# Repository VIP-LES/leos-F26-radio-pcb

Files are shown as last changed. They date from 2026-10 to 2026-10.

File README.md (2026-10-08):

# LEOS Radio PCB

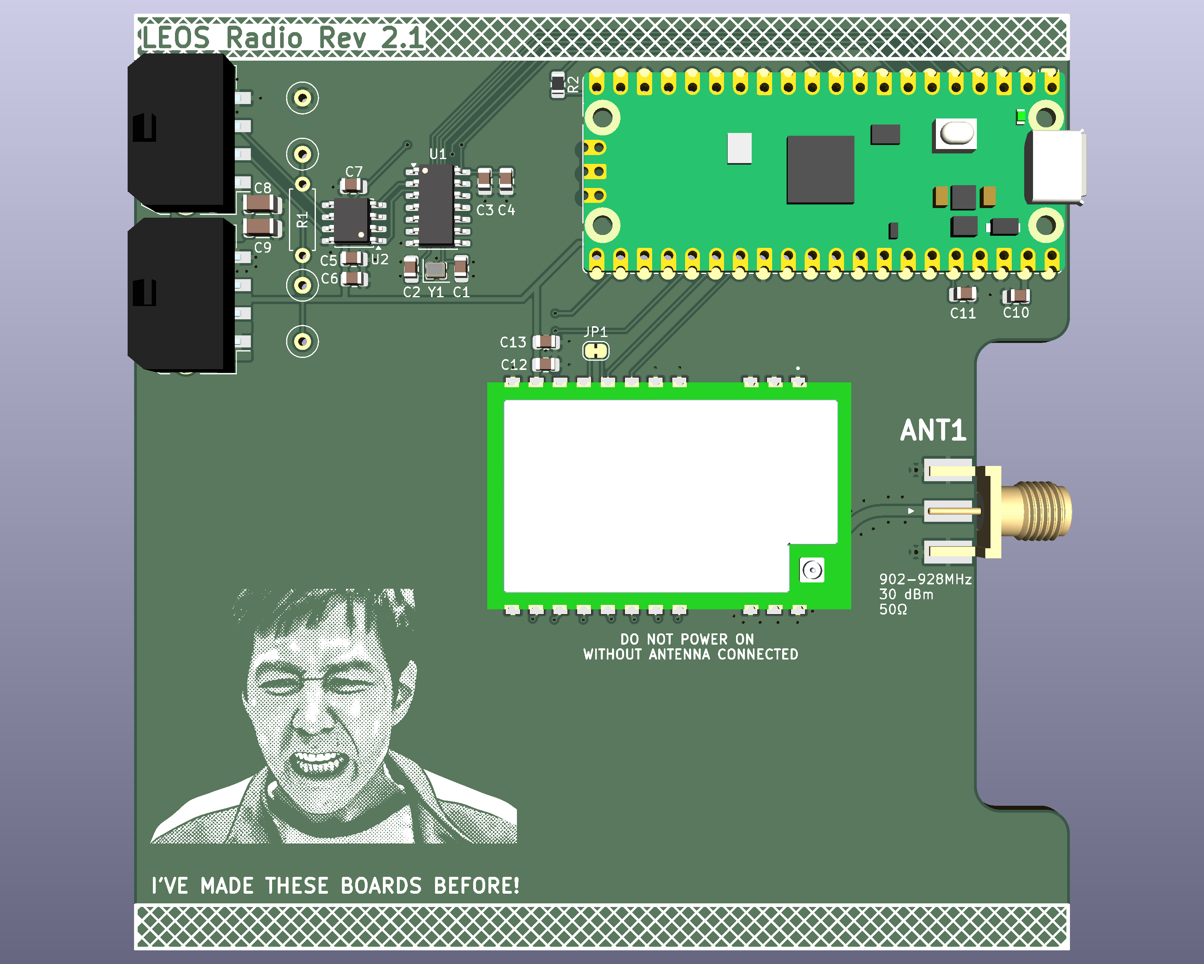
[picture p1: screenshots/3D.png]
3D render of the LEOS Radio PCB


This repository contains the KiCad schematic and PCB layout for the LEOS Radio PCB made fall 2026. The board integrates a Raspberry Pi Pico, an E22-900M30S LoRa radio module, and a CAN-FD interface.

The Raspberry Pi Pico communicates with the radio module through SPI1 and the MCP2518FD CAN-FD controller through SPI0. An MCP2562FD transceiver connects the CAN controller to the LEOS CAN bus. An SMA connector provides the connection for an external antenna.

## Board Overview
Main hardware functions:
- Wireless communication: E22-900M30S LoRa radio module provides wireless transmission and reception through an external antenna connected to the SMA connector.
- CAN-FD communication: MCP2518FD controller and MCP2562FD transceiver provide the interface to the LEOS CAN bus.
- Microcontroller control: Pico interfaces with the radio module and CAN controller through separate SPI buses. Additional GPIO connections provide radio reset, busy monitoring, interrupt, and receive-enable signals.

## Electrical Design
- Board supply: 5 V
- Microcontroller: Raspberry Pi Pico, as labeled in the schematic
- Radio module: E22-900M30S
- CAN-FD controller: MCP2518FD
- CAN-FD transceiver: MCP2562FD
- Bus connectors: Two four-pin MicroFit connectors

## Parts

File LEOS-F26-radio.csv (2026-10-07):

Reference | Qty | Value | Footprint | Manufacturer | MPN | Digikey | Description
A1 | 1 | RaspberryPi Pico | Module:RaspberryPi_Pico_Common_Unspecified | Pimoroni | PIM724 | 1778-PIM724-ND | Pimoroni Pico Plus 2
ANT1 | 1 | 900MHz SMA | Connector_Coaxial:SMA_Molex_73251-1153_EdgeMount_Horizontal | Molex | 0732511153 | 900-0732511153-ND | coaxial connector (BNC, SMA, SMB, SMC, Cinch/RCA, LEMO, ...)
C1,C2 | 2 | 10p | Capacitor_SMD:C_0805_2012Metric | Samsung Electro-Mechanics | CL21C100CBANNNC | 1276-2561-1-ND | 10pF 50V C0G/NP0 0805
C3,C5,C7,C10,C12 | 5 | 0.1u | Capacitor_SMD:C_0805_2012Metric | Samsung Electro-Mechanics | CL21B104KBCNNNC | 1276-1003-1-ND | 0.1uF 50V X7R 0805
C4,C6,C13 | 3 | 1u | Capacitor_SMD:C_0805_2012Metric | KEMET | C0805C105K3RACTU | 399-C0805C105K3RACTUCT-ND | CAP CER 1UF 25V X7R 0805
C8,C9 | 2 | 22u | Capacitor_SMD:C_1206_3216Metric | Samsung Electro-Mechanics | CL31B226MPHNNNE | 1276-3148-1-ND | 22uF 10V X7R 1206
C11 | 1 | 10u | Capacitor_SMD:C_0805_2012Metric | Samsung Electro-Mechanics | CL21B106KOQNNNE | 1276-2872-1-ND | CAP CER 10UF 16V X7R 0805
J1,J2 | 2 | MicroFit_1x4 | LEOS:Molex_MicroFit3.0_43650-0410_1x04_Horizontal | Molex | 0436500409 | WM1882CT-ND | Molex MicroFit3.0 1x4 Bus Connector
R2 | 1 | 10k | Resistor_SMD:R_0805_2012Metric | Vishay Dale | CRCW080510K0FKEA | 541-10.0KCCT-ND | RES SMD 10K OHM 1% 1/8W 0805
U1 | 1 | MCP2518FD | Package_SO:SOIC-14_3.9x8.7mm_P1.27mm | Microchip | MCP2518FDT-E/SL | MCP2518FDT-E/SLCT-ND | External CAN FD Controller with SPI Interface
U2 | 1 | MCP2562FD | Package_SO:SOIC-8_3.9x4.9mm_P1.27mm | Microchip | MCP2562FDT-H/SN | MCP2562FDT-E/SNCT-ND | High-Speed CAN Flexible Data Rate Transceiver
U3 | 1 | E22-900M30S | LEOS:XCVR_E22-900M30S |  |  |  | SX1262 868/915 MHz 1w SPI LoRa Module
Y1 | 1 | 40 MHz | Crystal:Crystal_SMD_2016-4Pin_2.0x1.6mm | ECS Inc, | ECS-400-10-37B2-CKY-TR | 50-ECS-400-10-37B2-CKY-TRCT-ND | 40 MHz ±10ppm Crystal 10pF 40 Ohms SMD2016

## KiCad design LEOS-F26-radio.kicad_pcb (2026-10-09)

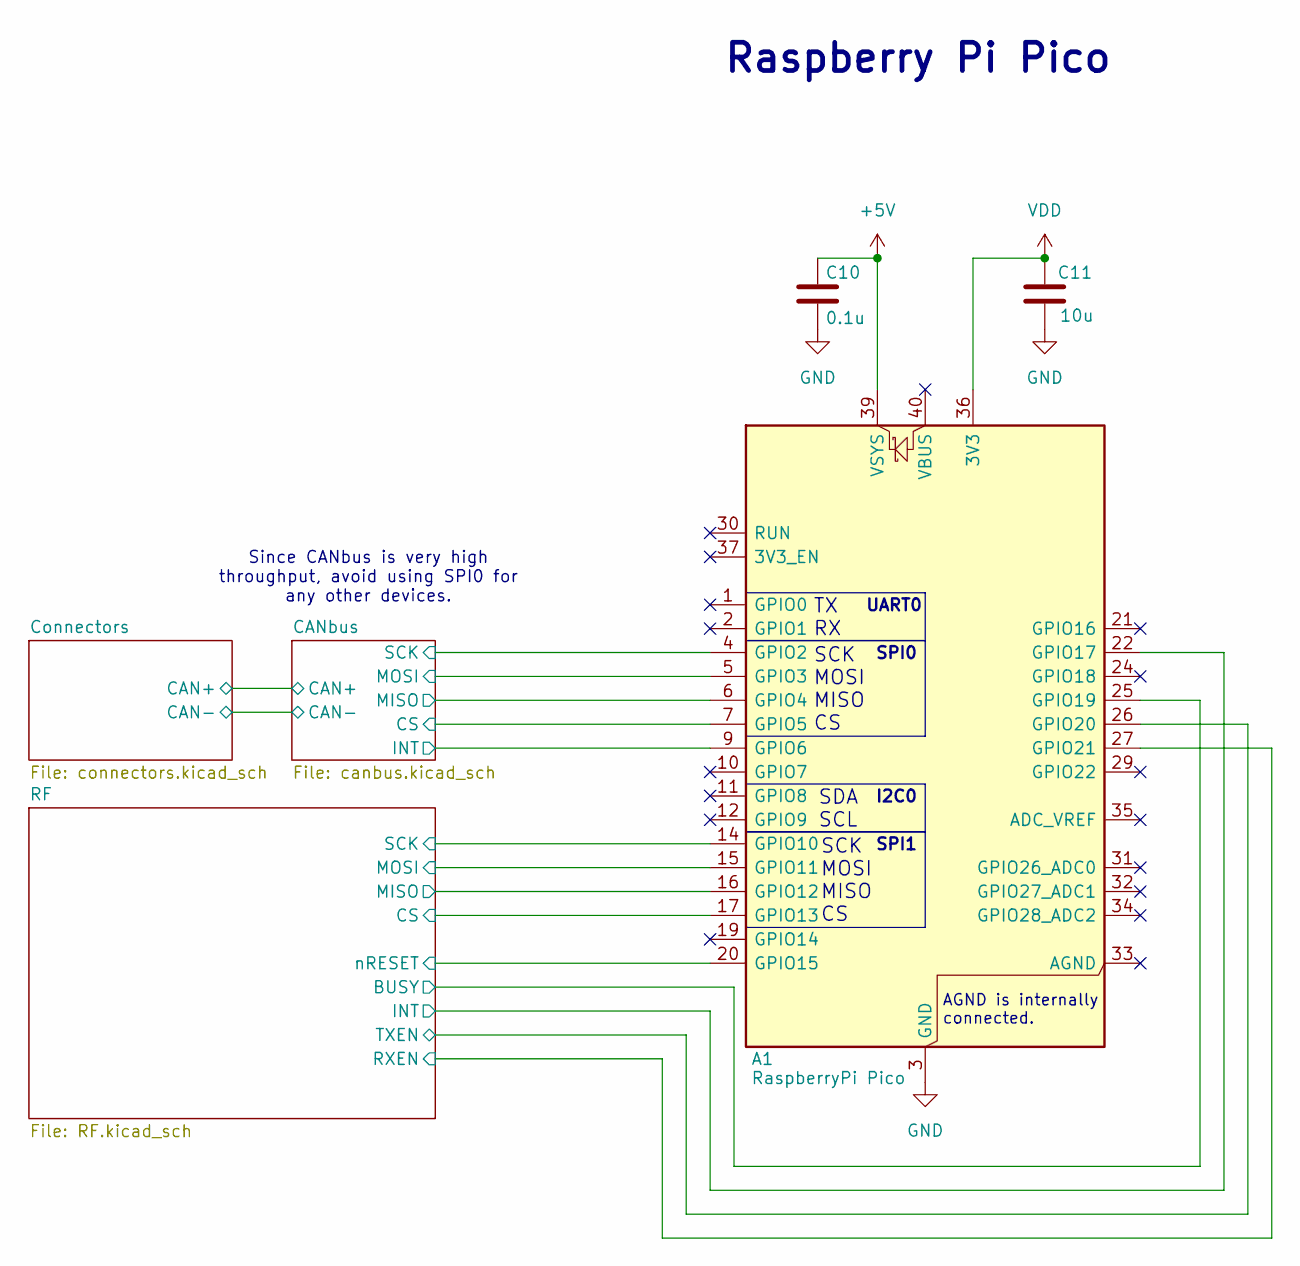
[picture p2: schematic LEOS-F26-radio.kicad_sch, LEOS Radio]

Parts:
A1: RaspberryPi Pico; RaspberryPi_Pico_Common_Unspecified; MPN PIM724; Digikey 1778-PIM724-ND
C10: 0.1u; C_0805_2012Metric; MPN CL21B104KBCNNNC; Digikey 1276-1003-1-ND
C11: 10u; C_0805_2012Metric; MPN CL21B106KOQNNNE; Digikey 1276-2872-1-ND

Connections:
+5V: A1.39 (VSYS), C10.1; also elsewhere on the board
/CANbus/CS: A1.7 (GPIO5); also elsewhere on the board
/CANbus/INT: A1.9 (GPIO6); also elsewhere on the board
/CANbus/MISO: A1.6 (GPIO4); also elsewhere on the board
/CANbus/MOSI: A1.5 (GPIO3); also elsewhere on the board
/CANbus/SCK: A1.4 (GPIO2); also elsewhere on the board
/RF/BUSY: A1.25 (GPIO19); also elsewhere on the board
/RF/CS: A1.17 (GPIO13); also elsewhere on the board
/RF/INT: A1.22 (GPIO17); also elsewhere on the board
/RF/MISO: A1.16 (GPIO12); also elsewhere on the board
/RF/MOSI: A1.15 (GPIO11); also elsewhere on the board
/RF/RXEN: A1.27 (GPIO21); also elsewhere on the board
/RF/SCK: A1.14 (GPIO10); also elsewhere on the board
/RF/TXEN: A1.26 (GPIO20); also elsewhere on the board
/RF/nRESET: A1.20 (GPIO15); also elsewhere on the board
GND: A1.3 (GND), A1.8 (GND), A1.13 (GND), A1.18 (GND), A1.23 (GND), A1.28 (GND), A1.38 (GND), C10.2, C11.2; also elsewhere on the board
VDD: A1.36 (3V3), C11.1; also elsewhere on the board

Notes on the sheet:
SPI1
Raspberry Pi Pico
SCK MOSI MISO CS
Since CANbus is very high throughput, avoid using SPI0 for any other devices.
SPI0
SDA SCL
TX RX
UART0
I2C0
AGND is internally connected.

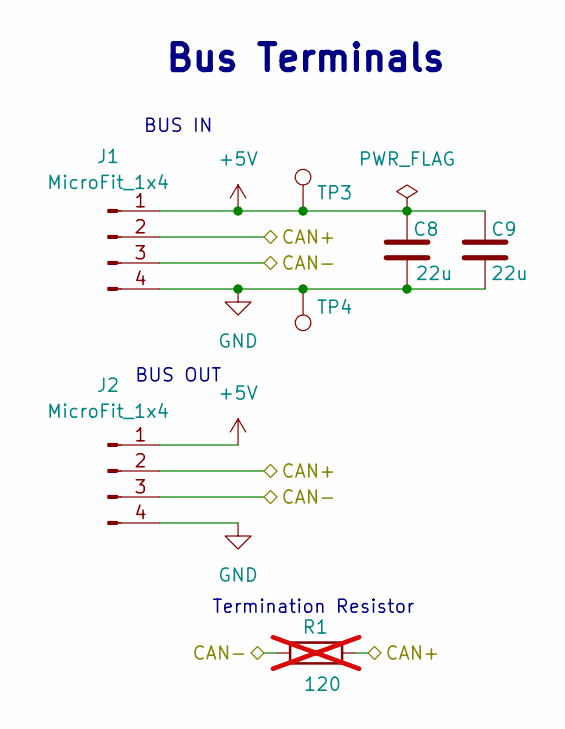
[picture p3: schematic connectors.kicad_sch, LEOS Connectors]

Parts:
C8, C9: 22u; C_1206_3216Metric; MPN CL31B226MPHNNNE; Digikey 1276-3148-1-ND
J1, J2: MicroFit_1x4; Molex_MicroFit3.0_43650-0410_1x04_Horizontal; MPN 0436500409; Digikey WM1882CT-ND
R1: 120; R_Axial_DIN0207_L6.3mm_D2.5mm_P7.62mm_Horizontal; MPN CF14JT120R; Digikey CF14JT120RCT-ND; not fitted
TP3: 5V Test Point; TestPoint_Loop_D2.60mm_Drill0.9mm_Beaded; MPN 5000; Digikey 36-5000-ND
TP4: GND Test Point; TestPoint_Loop_D2.60mm_Drill0.9mm_Beaded; MPN 5001; Digikey 36-5001-ND

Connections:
+5V: C8.1, C9.1, J1.1, J2.1, TP3.1 (1_1); also elsewhere on the board
/CANbus/CAN+: J1.2, J2.2, R1.2; also elsewhere on the board
/CANbus/CAN-: J1.3, J2.3, R1.1; also elsewhere on the board
GND: C8.2, C9.2, J1.4, J2.4, TP4.1 (1_1); also elsewhere on the board

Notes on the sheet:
BUS OUT
Bus Terminals
BUS IN
Termination Resistor

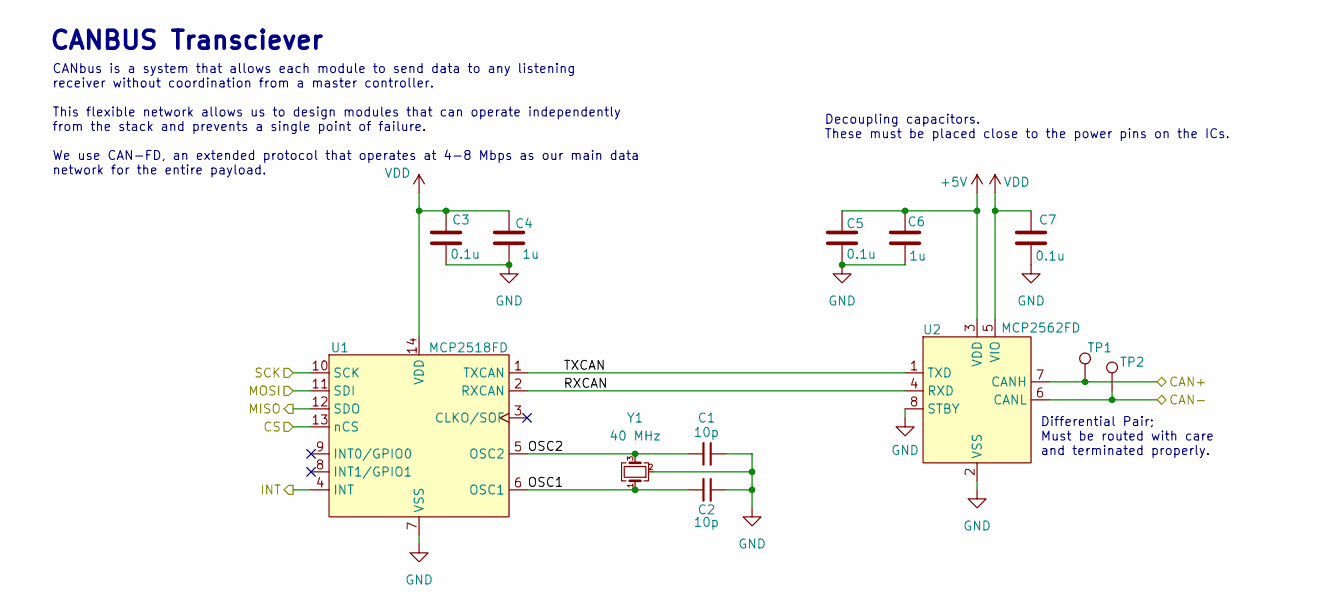
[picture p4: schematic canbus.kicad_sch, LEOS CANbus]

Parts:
C1, C2: 10p; C_0805_2012Metric; MPN CL21C100CBANNNC; Digikey 1276-2561-1-ND
C3, C5, C7: 0.1u; C_0805_2012Metric; MPN CL21B104KBCNNNC; Digikey 1276-1003-1-ND
C4, C6: 1u; C_0805_2012Metric; MPN C0805C105K3RACTU; Digikey 399-C0805C105K3RACTUCT-ND
TP1: CAN-H Test Point; TestPoint_Loop_D2.60mm_Drill0.9mm_Beaded; MPN 5004; Digikey 36-5004-ND
TP2: CAN-L Test Point; TestPoint_Loop_D2.60mm_Drill0.9mm_Beaded; MPN 5116; Digikey 36-5116-ND
U1: MCP2518FD; SOIC-14_3.9x8.7mm_P1.27mm; MPN MCP2518FDT-E/SL; LCSC C626758
U2: MCP2562FD; SOIC-8_3.9x4.9mm_P1.27mm; MPN MCP2562FDT-H/SN; LCSC C511335
Y1: 40 MHz; Crystal_SMD_2016-4Pin_2.0x1.6mm; MPN ECS-400-10-37B2-CKY-TR; Digikey 50-ECS-400-10-37B2-CKY-TRCT-ND

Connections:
+5V: C5.1, C6.1, U2.3 (VDD); also elsewhere on the board
/CANbus/CAN+: TP1.1 (1_1), U2.7 (CANH); also elsewhere on the board
/CANbus/CAN-: TP2.1 (1_1), U2.6 (CANL); also elsewhere on the board
/CANbus/CS: U1.13 (nCS); also elsewhere on the board
/CANbus/INT: U1.4 (INT); also elsewhere on the board
/CANbus/MISO: U1.12 (SDO); also elsewhere on the board
/CANbus/MOSI: U1.11 (SDI); also elsewhere on the board
/CANbus/OSC1: C2.2, U1.6 (OSC1), Y1.1
/CANbus/OSC2: C1.2, U1.5 (OSC2), Y1.3
/CANbus/RXCAN: U1.2 (RXCAN), U2.4 (RXD)
/CANbus/SCK: U1.10 (SCK); also elsewhere on the board
/CANbus/TXCAN: U1.1 (TXCAN), U2.1 (TXD)
GND: C1.1, C2.1, C3.2, C4.2, C5.2, C6.2, C7.2, U1.7 (VSS), U2.2 (VSS), U2.8 (STBY), Y1.2 (G), Y1.4 (G); also elsewhere on the board
VDD: C3.1, C4.1, C7.1, U1.14 (VDD), U2.5 (VIO); also elsewhere on the board

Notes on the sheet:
Differential Pair; Must be routed with care and terminated properly.
CANBUS Transciever
CANbus is a system that allows each module to send data to any listening receiver without coordination from a master controller. This flexible network allows us to design modules that can operate independently from the stack and prevents a single point of failure. We use CAN-FD, an extended protoco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
Decoupling capacitors. These must be placed close to the power pins on the ICs.

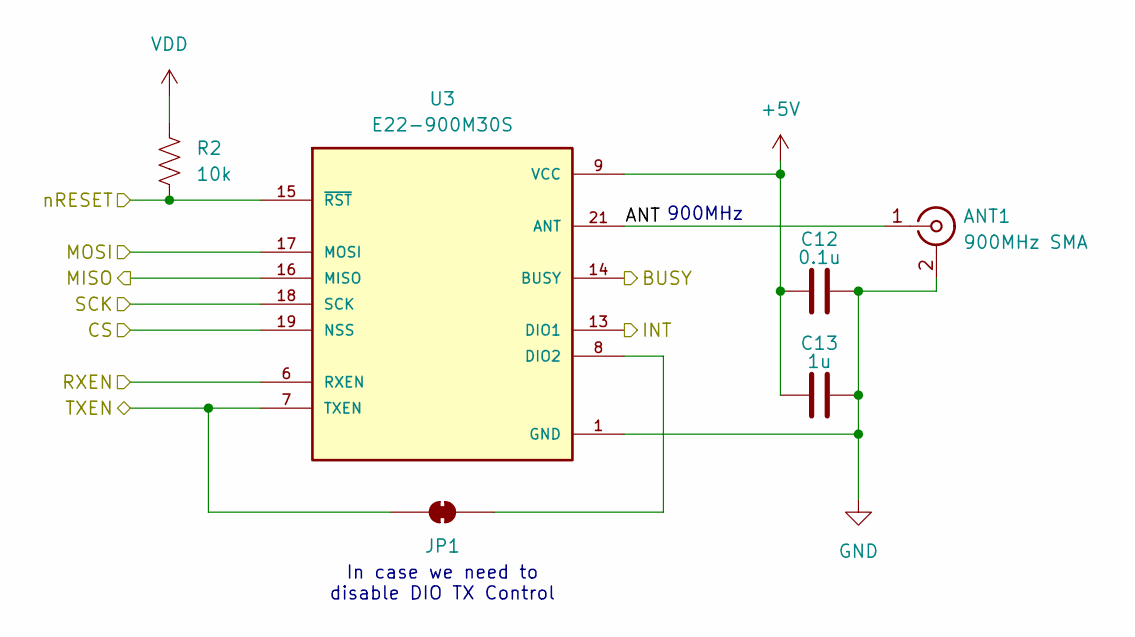
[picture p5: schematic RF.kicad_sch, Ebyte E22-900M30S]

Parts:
ANT1: 900MHz SMA; SMA_Molex_73251-1153_EdgeMount_Horizontal; MPN 0732511153; Digikey 900-0732511153-ND
C12: 0.1u; C_0805_2012Metric; MPN CL21B104KBCNNNC; Digikey 1276-1003-1-ND
C13: 1u; C_0805_2012Metric; MPN C0805C105K3RACTU; Digikey 399-C0805C105K3RACTUCT-ND
JP1: SolderJumper_2_Bridged; SolderJumper-2_P1.3mm_Bridged_RoundedPad1.0x1.5mm
R2: 10k; R_0805_2012Metric; MPN CRCW080510K0FKEA; Digikey 541-10.0KCCT-ND
U3: E22-900M30S; XCVR_E22-900M30S

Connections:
+5V: C12.1, C13.1, U3.9 (VCC), U3.10 (VCC); also elsewhere on the board
/RF/ANT: ANT1.1 (In), U3.21 (ANT)
/RF/BUSY: U3.14 (BUSY); also elsewhere on the board
/RF/CS: U3.19 (NSS); also elsewhere on the board
/RF/INT: U3.13 (DIO1); also elsewhere on the board
/RF/MISO: U3.16 (MISO); also elsewhere on the board
/RF/MOSI: U3.17 (MOSI); also elsewhere on the board
/RF/RXEN: U3.6 (RXEN); also elsewhere on the board
/RF/SCK: U3.18 (SCK); also elsewhere on the board
/RF/TXEN: JP1.1 (A), U3.7 (TXEN); also elsewhere on the board
/RF/nRESET: R2.2, U3.15 (~RST); also elsewhere on the board
GND: ANT1.2 (Ext), C12.2, C13.2, U3.1 (GND), U3.2 (GND), U3.3 (GND), U3.4 (GND), U3.5 (GND), U3.11 (GND), U3.12 (GND), U3.20 (GND), U3.22 (GND); also elsewhere on the board
unnamed: JP1.2 (B), U3.8 (DIO2)
VDD: R2.1; also elsewhere on the board

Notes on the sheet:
In case we need to disable DIO TX Control
900MHz

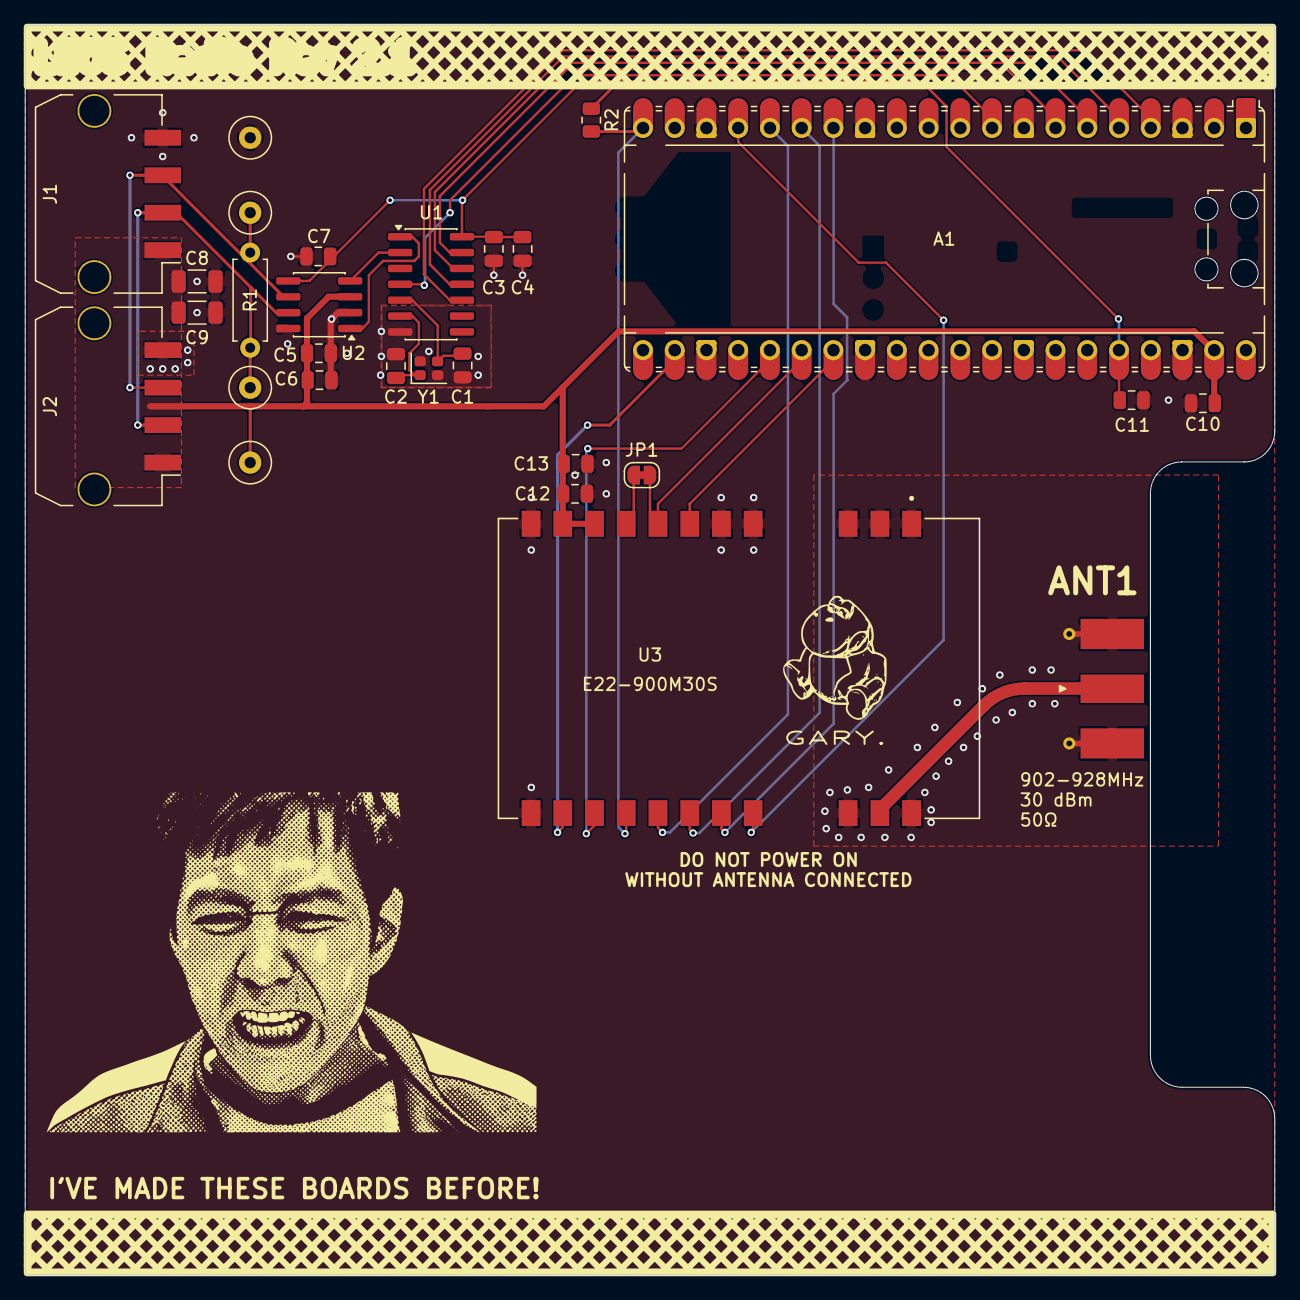
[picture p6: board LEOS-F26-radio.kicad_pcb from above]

Board: 2 copper layers, 100.0 x 100.0 mm, 28 parts (0 on the bottom side), 25 nets.

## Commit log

2026-10-05 Add LEOS-F26-radio.kicad_dru file
2026-10-05 Add LEOS-F26-radio.kicad_pro file
2026-10-07 schematic and routing updated
    [LEOS-F26-radio.csv, LEOS-F26-radio.kicad_pcb, LEOS-F26-radio.kicad_sch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]
2026-10-08 Revised README for LEOS Radio PCB details
2026-10-09 added silkscreen
    [LEOS-F26-radio.kicad_pcb]
2026-10-09 Change radio reset pullup to IO voltage, fix net labels
    [LEOS-F26-radio.kicad_sch, RF.kicad_sch, canbus.kicad_sch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]
2026-10-09 Update routing and edge cuts for RF. Rearrange silkscreen
    [LEOS-F26-radio.kicad_pcb]
2026-10-09 Update fills for final production, set out dir
    [LEOS-F26-radio.kicad_pcb]
